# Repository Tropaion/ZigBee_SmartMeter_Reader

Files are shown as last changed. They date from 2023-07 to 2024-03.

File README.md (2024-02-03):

# ZigBee_SmartMeter_Reader
This is an open-source ZigBee device based on the new ESP32-C6 to collect data from smartmeters using the DLMS/COSEM protocol.

Ever since I got the smartmeter "Sagemcom T-210D" with the P1 user interface, I wanted to integrate it into my ZigBee network.
Since I didn't find any existing solution, I decided to develop my own.

If someone is interested in buying an assembled PCB, pm me.
Currently I have one board with external antenna available.

THE PROJECT IS STILL WIP.

# Hardware
View the latest [PCB Interactive BOM](https://htmlpreview.github.io/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).

You can also view the latest [Schematic](https://kicanvas.org/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) or [Layout](https://kicanvas.org/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).

The same hardware could also be used with WLAN and ESPHome.

<p float="left">
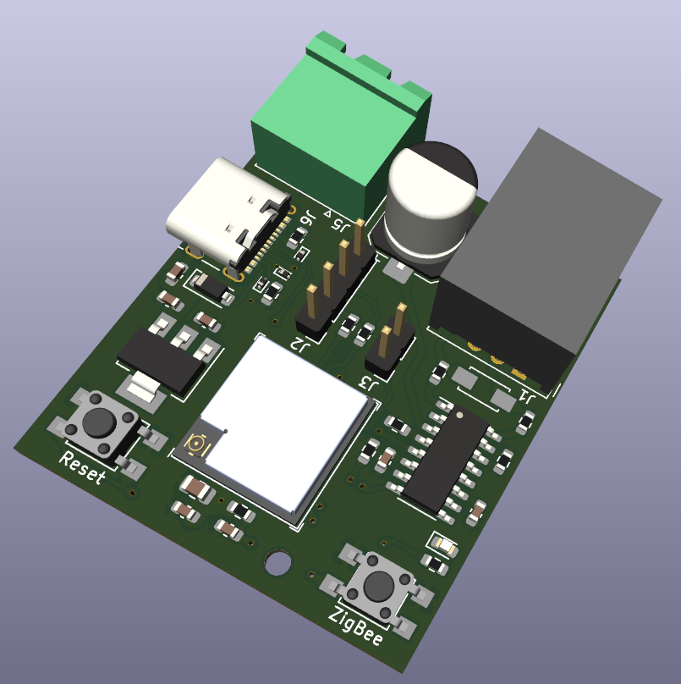
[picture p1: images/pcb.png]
  
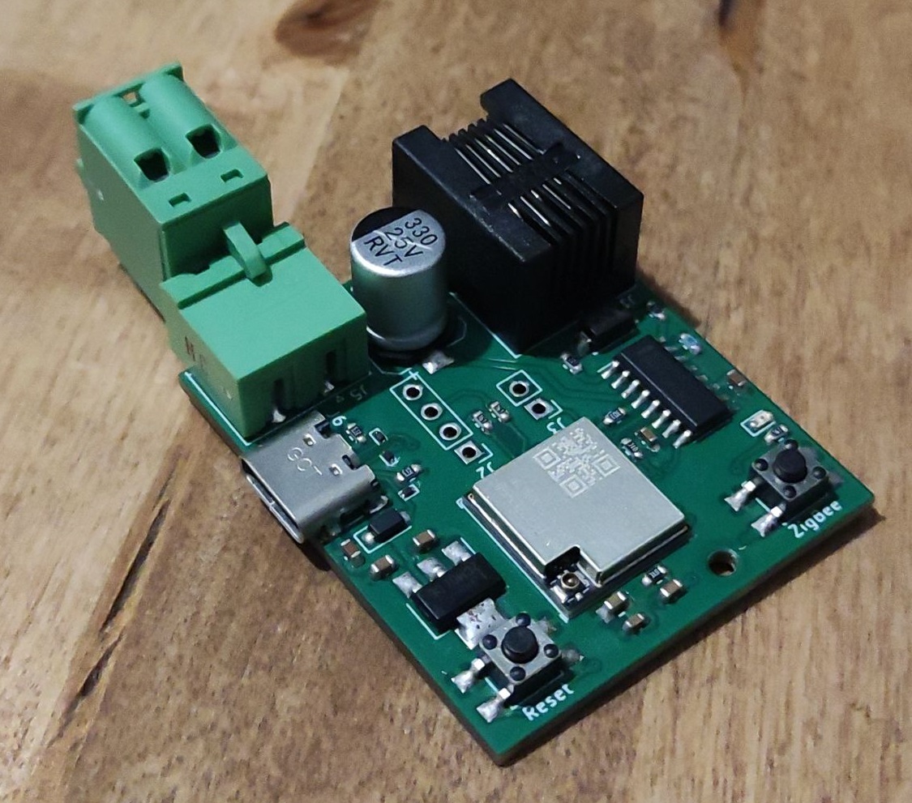
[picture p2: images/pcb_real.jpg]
  
</p>

For this project, I used the [ESP32-C6-MINI-1U](https://www.espressif.com/sites/default/files/documentation/esp32-c6-mini-1_mini-1u_datasheet_en.pdf).
I chose the version with an external antenna, since, in most cases, the devices will be mounted in an isolated meter box. And, since many of them are made of metal (Faraday cage), like in my case, 
I opted for an external antenna to mount on the outside of the meter box.

To provide easy flashing and debugging the USB-C-Socket is connected to the ESP internal USB-JTAG-Converter.
In the case that the converter is not working, the UART0 programming interface is connected to J2 and J3, which will not be assembled.

For production use in the meter box, only the 5V supply terminal (J5) which in my case will be connected to a 5V DIN Power Supply and RJ12 (J1) cable going to the smartmeter is needed.

Since most smartmeters send encrypted data, you probably need to request an decryption key from your provider.
This key has to be configured in the software. The current plan for this is to provide a simple configuration terminal which is accessible via the USB-C-Socket.

# Software
The software will be separated into three core components/libraries.
Each will be individually tested and then combined.
- [x] human_interface - handles button input and led (working)
- [x] zigbee - handles zigbee basic functions
- [x] zigbee_electricity_meter - handles everything zigbee and electricity meter related (cluster)
- [ ] smartmeter - read data via uart, parse layers and decrypt data

Possible additional functionalities:
- [ ] zigbee_ota - updating firmware via zigbee
- [ ] configuration_console - usb console to configure device (decryption key)

OR
- [ ] zigbee custom configuration cluster - cluster configure device (decryption key)

## Structure of SmartMeter data
How the data is handled is a bit complicated and consists of three layers:
- MBUS-Layer
- DLMS-Layer
- OBIS-Layer

Each layer will be handled by a parser.

See the diagram to understand the structure and how the parser handles the data:
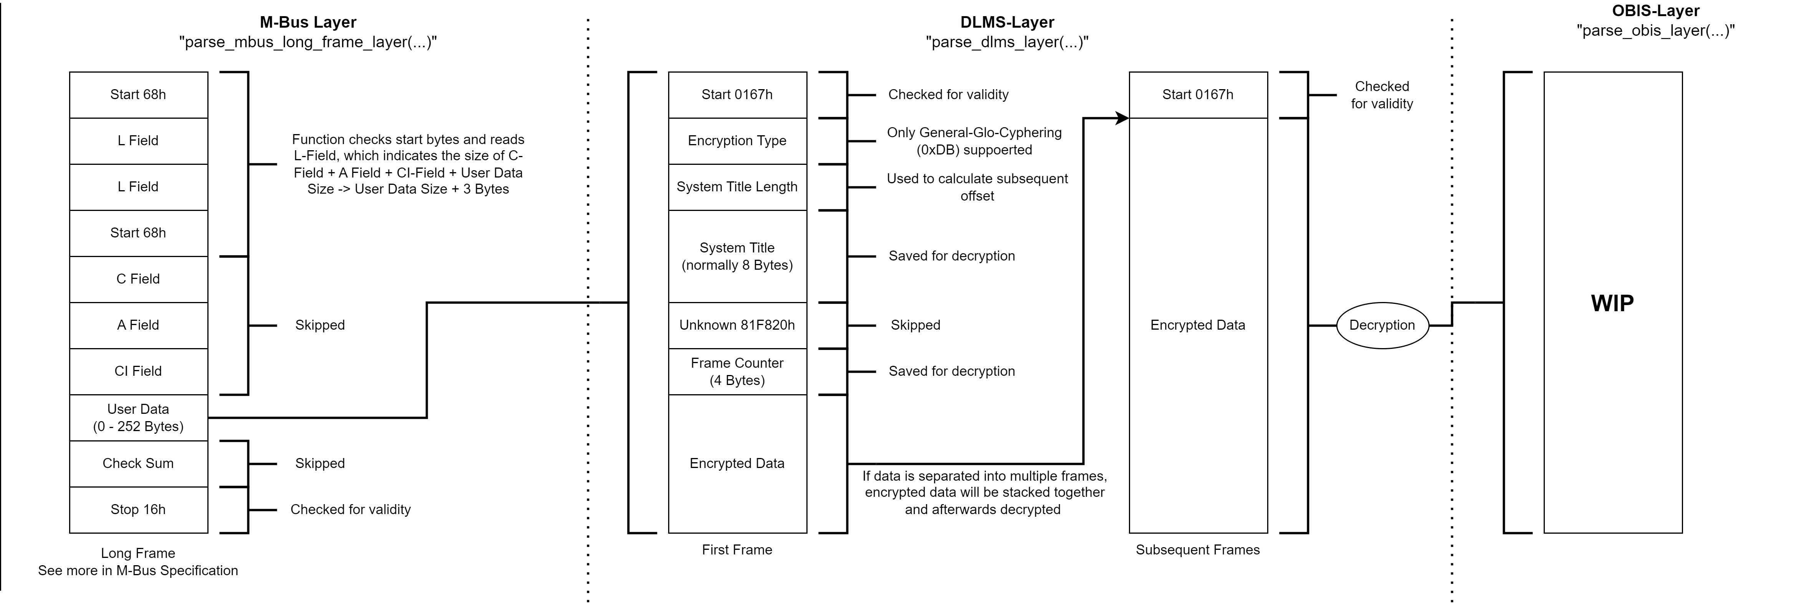
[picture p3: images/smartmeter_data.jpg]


## Sources
 * [esphome-dlms-meter](https://github.com/DomiStyle/esphome-dlms-meter)
 * [SmartMeter P1 Interface](https://www.netz-noe.at/Download-(1)/Smart-Meter/218_9_SmartMeter_Kundenschnittstelle_lektoriert_14.aspx)
 * [M-Bus Specification, Page 22+](https://m-bus.com/assets/downloads/MBDOC48.PDF)
 * [ZigBee Home Automation Profile](https://community.nxp.com/pwmxy87654/attachments/pwmxy87654/wireless-connectivity/698/1/075367r03ZB_AFG-Home_Automation_Profile_for_Public_Download.pdf)
 * [ZigBee Cluster Library Specification](https://zigbeealliance.org/wp-content/uploads/2019/12/07-5123-06-zigbee-cluster-library-specification.pdf)

# Enclosue
The first version of the enclosure is released and now in printing.

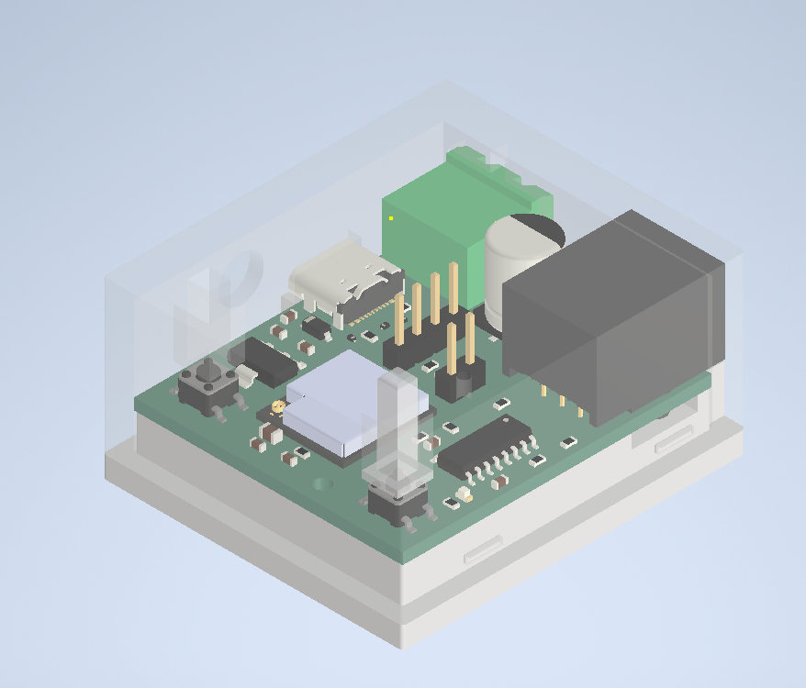
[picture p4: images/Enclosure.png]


# Attribution
Thanks to EspressIf for sponsoring two samples of [ESP32-C6-MINI-1U](https://www.espressif.com/sites/default/files/documentation/esp32-mini-1_datasheet_en.pdf).

Thanks to [PCBWay](https://www.pcbway.com/) for sponsoring the production of the PCB and Stencil for v0.2. It was my first time using their service and they have nice customer service and great build quality. The image in the hardware section shows the result of v0.2.

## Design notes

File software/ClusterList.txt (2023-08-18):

https://docs.espressif.com/projects/esp-zigbee-sdk/en/latest/esp32/introduction.html
https://zigbeealliance.org/wp-content/uploads/2019/12/07-5123-06-zigbee-cluster-library-specification.pdf

 == Values received from SmartMeter and fitting Cluster + Attribute for it ==
0x0702 - Metering Clusteer (Smart Energy -> Metering), S. 592 - not supported

Attribute Set 0x00: Reading Information Set (S. 594)
power factor: 0x0006 PowerFactor
active energy A+ (Wh): ????
active energy A- (Wh): ????
electrical power P- (W): ????

0x0B04 - Electrical Measurement Cluster (Measurement and Sending), S. 298 - already supported
https://docs.espressif.com/projects/esp-zigbee-sdk/en/latest/esp32/api-reference/zcl/esp_zigbee_zcl_electrical_meas.html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

Attribute Set 0x03: AC (Non-phase Specific) Measurements (S. 303)
electrical power P+ (W): 0x0304 TotalActivePower

Attribute Set 0x05: AC (Single Phase or Phase A) Measurements (S. 306)
voltage L1: 0x0505 RMSVoltage
current L1: 0x0508 RMSCurrent

Attribute Set 0x09: AC Phase B Measurements (S. 313)
voltage L2: 0x0905 RMSVoltagePhB
current L2: 0x0908 RMSCurrentPhB

Attribute Set 0x0A: AC Phase C Measurements
voltage L3: 0x0A05 RMSVoltagePhB
current L3: 0x0A08 RMSCurrentPhB

Similar device signature:
{
  "node_descriptor": "NodeDescriptor(logical_type=<LogicalType.Router: 1>, complex_descriptor_available=0, user_descriptor_available=0, reserved=0, aps_flags=0, frequency_band=<FrequencyBand.Freq2400MHz: 8>, mac_capability_flags=<MACCapabilityFlags.FullFunctionDevice|MainsPowered|RxOnWhenIdle|AllocateAddress: 142>, manufacturer_code=4417, maximum_buffer_size=66, maximum_incoming_transfer_size=66, server_mask=10752, maximum_outgoing_transfer_size=66, descriptor_capability_field=<DescriptorCapability.NONE: 0>, *allocate_address=True, *is_alternate_pan_coordinator=False, *is_coordinator=False, *is_end_device=False, *is_full_function_device=True, *is_mains_powered=True, *is_receiver_on_when_idle=True, *is_router=True, *is_security_capable=False)",
  "endpoints": {
    "1": {
      "profile_id": "0x0104",
      "device_type": "0x010a",
      "input_clusters": [
        "0x0000",
        "0x0003",
        "0x0004",
        "0x0005",
        "0x0006",
        "0x0702",
        "0x0b04",
        "0xe000",
        "0xe001"
      ],
      "output_clusters": [
        "0x000a",
        "0x0019"
      ]
    }
  },
  "manufacturer": "_TZ3000_2putqrmw",
  "model": "TS011F",
  "class": "zhaquirks.tuya.ts011f_plug.Plug"
}

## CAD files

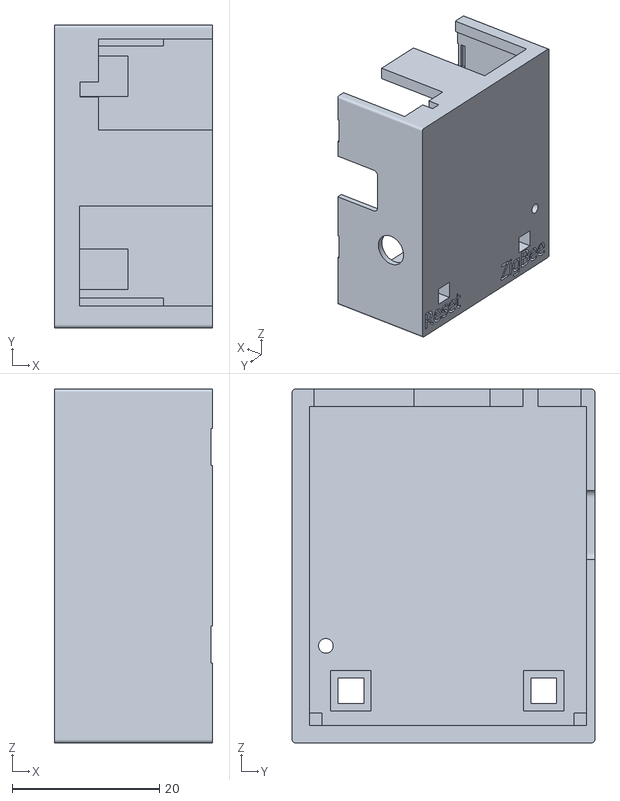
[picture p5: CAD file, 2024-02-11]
enclosure/external_antenna/Enclosure_Top.stl
21.5 x 41.2 x 48.1

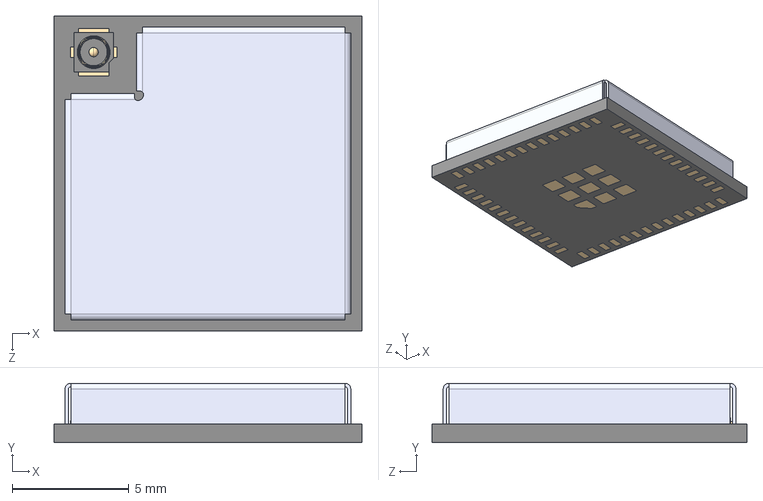
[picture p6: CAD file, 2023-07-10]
hardware/external_antenna/custom_components/3d/ESP32-MINI-1U-N4.STEP
13.2 x 2.55 x 13.5 mm

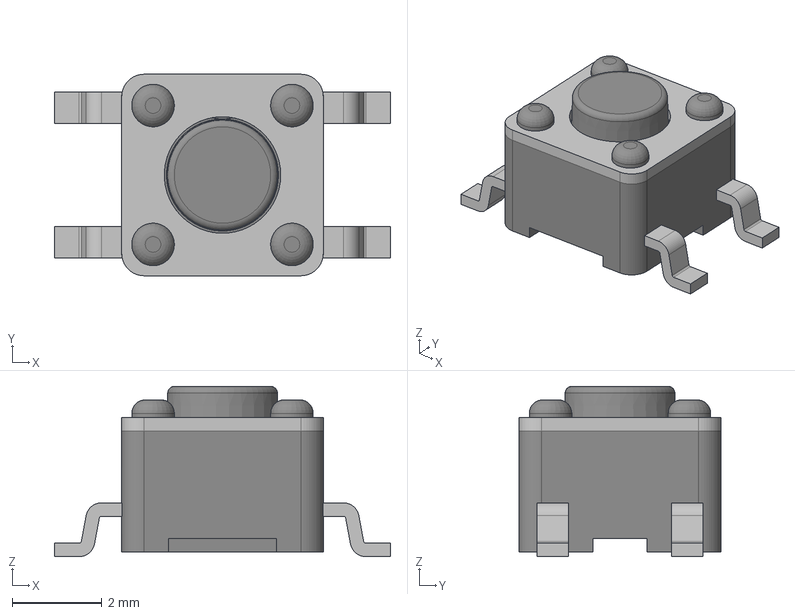
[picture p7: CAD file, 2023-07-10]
hardware/onboard_antenna/custom_components/3d/SW_SPST_TL3305A.step
7.50 x 4.50 x 3.80 mm

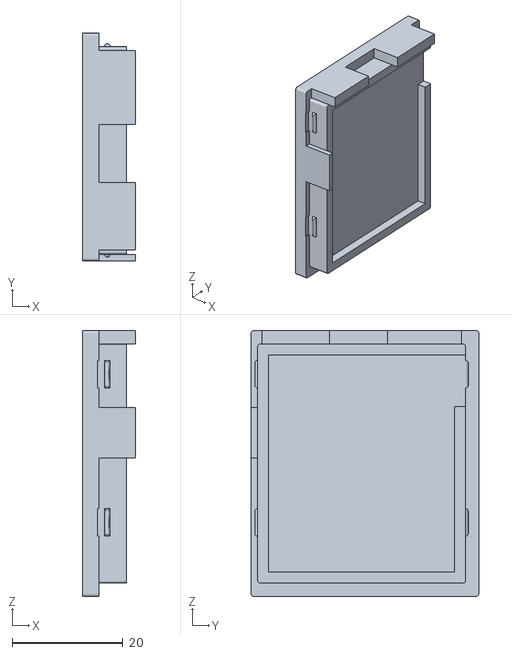
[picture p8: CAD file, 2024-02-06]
enclosure/external_antenna/Enclosure_Bottom.stl
9.60 x 41.2 x 48.1

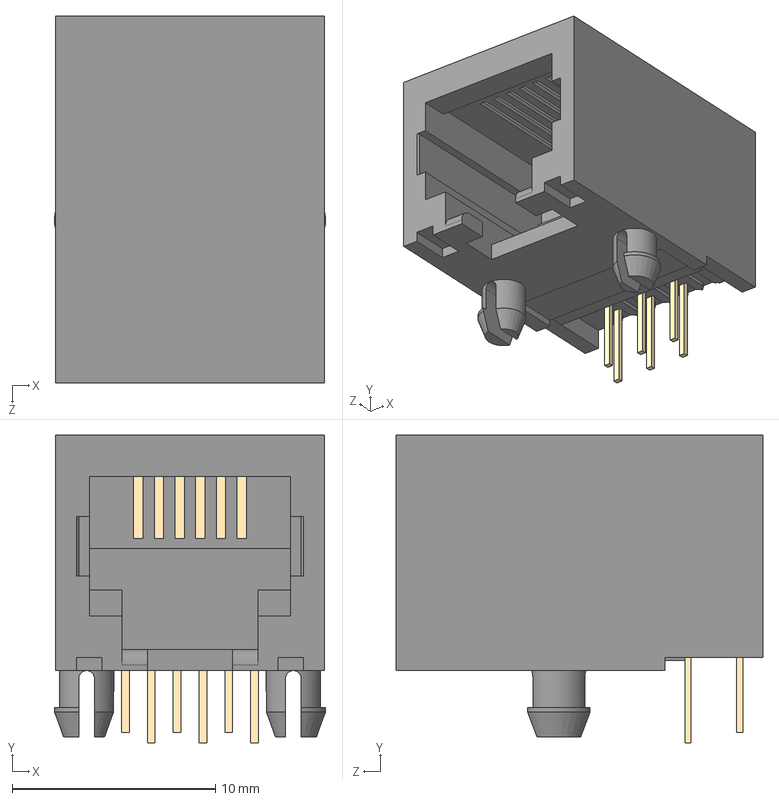
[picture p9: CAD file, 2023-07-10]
hardware/external_antenna/custom_components/3d/RJ12.step
13.3 x 15.1 x 18.0 mm

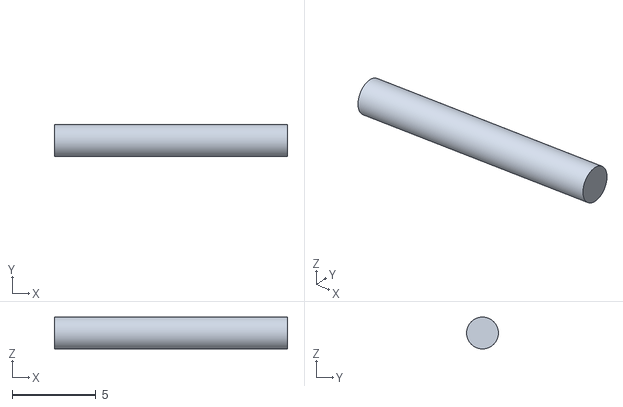
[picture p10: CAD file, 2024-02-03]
enclosure/external_antenna/Enclosure_Lightsaber.stl
13.9 x 1.90 x 1.90

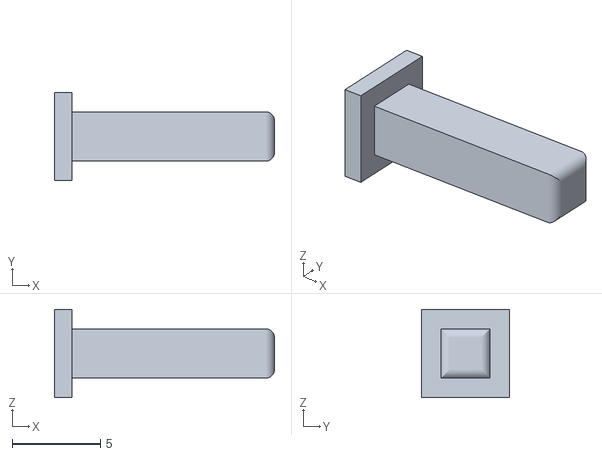
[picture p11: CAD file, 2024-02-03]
enclosure/external_antenna/Enclosure_Button.stl
12.5 x 5.00 x 5.00

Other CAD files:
enclosure/external_antenna/Enclosure_Bottom.ipt
enclosure/external_antenna/Enclosure_Button.ipt
enclosure/external_antenna/Enclosure_Lightsaber.ipt
enclosure/external_antenna/Enclosure_Top.ipt

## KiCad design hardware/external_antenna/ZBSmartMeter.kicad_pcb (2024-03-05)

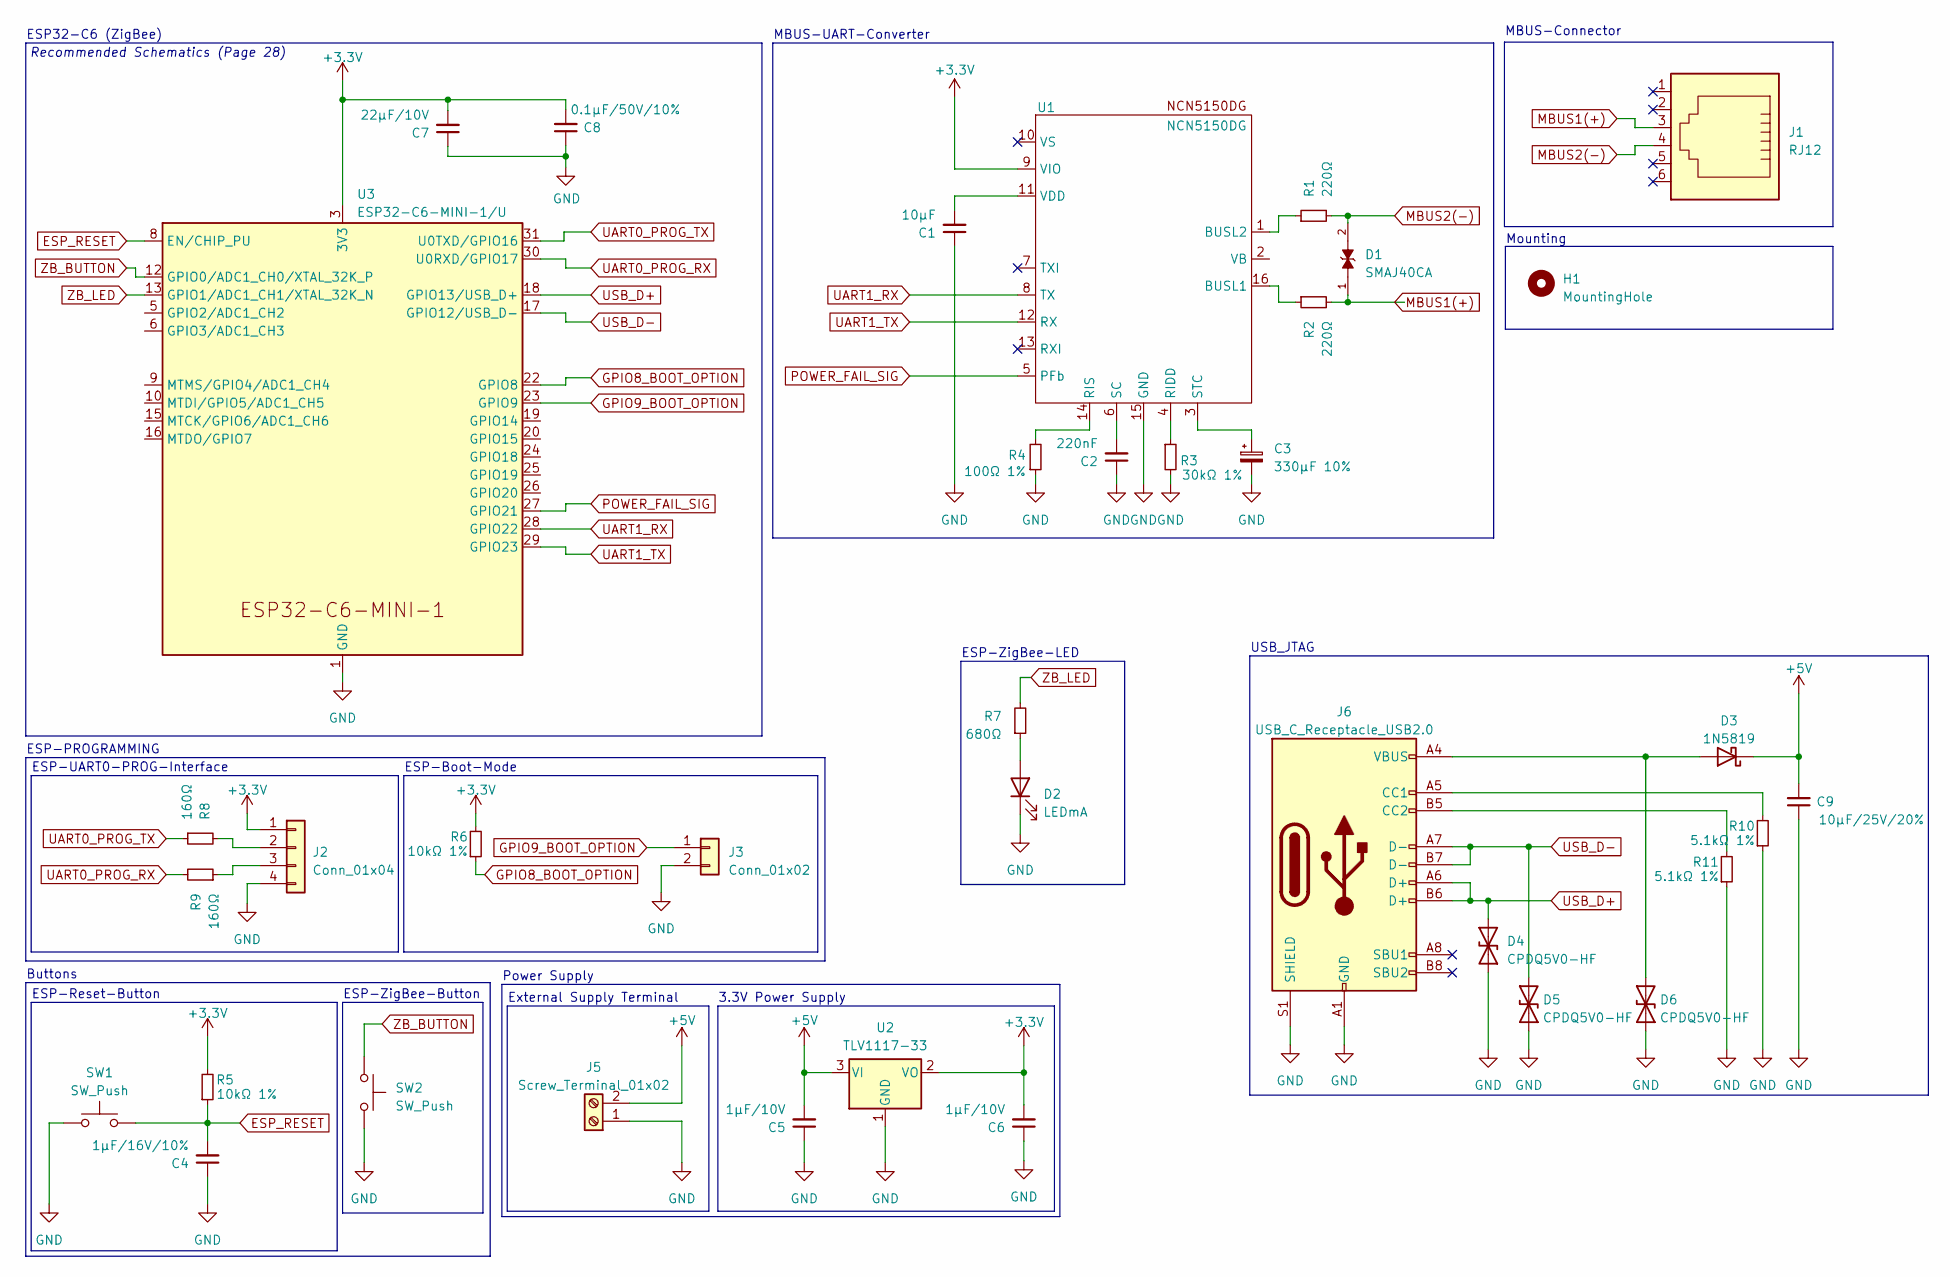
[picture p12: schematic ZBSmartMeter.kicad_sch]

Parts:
C1: 10µF; C_0603_1608Metric
C2: 220nF; C_0603_1608Metric
C3: 330µF 10%; CP_Elec_8x10.5
C4: 1µF/16V/10%; C_0603_1608Metric
C5, C6: 1µF/10V; C_0603_1608Metric
C7: 22µF/10V; C_0805_2012Metric
C8: 0.1µF/50V/10%; C_0603_1608Metric
C9: 10µF/25V/20%; C_0603_1608Metric
D1: SMAJ40CA; DIOM4325X250N; PARTREV S2102; Mouser 576-SMAJ40CA
D2: LEDmA; LED_0603_1608Metric
D3: 1N5819; D_SOD-123; Mouser 621-1N5819HW-F
D4, D5, D6: CPDQ5V0-HF; D_SOD-923; Mouser 750-CPDQ5V0-HF
H1: MountingHole; MountingHole_2.2mm_M2
J1: RJ12; RJ12_Amphenol_54601; Mouser 649-54601-906WPLF
J2: Conn_01x04; PinHeader_1x04_P2.54mm_Vertical
J3: Conn_01x02; PinHeader_1x02_P2.54mm_Vertical
J5: Screw_Terminal_01x02; PhoenixContact_MSTBA_2,5_2-G_1x02_P5.00mm_Horizontal; Mouser 651-1923759 and 651-1942154
J6: USB_C_Receptacle_USB2.0; USB_C_Receptacle_GCT_USB4105-xx-A_16P_TopMnt_Horizontal; Mouser 640-USB4105-GF-A
R1, R2: 220Ω; R_0603_1608Metric
R3: 30kΩ 1%; R_0603_1608Metric
R4: 100Ω 1%; R_0603_1608Metric
R5, R6: 10kΩ 1%; R_0603_1608Metric
R7: 680Ω; R_0603_1608Metric
R8, R9: 160Ω; R_0603_1608Metric
R10, R11: 5.1kΩ 1%; R_0603_1608Metric
SW1, SW2: SW_Push; SW_SPST_TL3305A; Mouser 612-TL3305AF160QG
U1: NCN5150DG; SOIC-16_3.9x9.9mm_P1.27mm; Mouser 863-NCN5150DR2G
U2: TLV1117-33; SOT-223-3_TabPin2; Mouser 595-TLV1117LV33DCYT
U3: ESP32-C6-MINI-1/U; ESP32-C6-MINI-1U

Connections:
+3.3V: C6.2, C7.2, C8.2, J2.1, R5.2, R6.2, U1.9 (VIO), U2.2 (VO), U3.3 (3V3)
+5V: C5.2, C9.2, D3.1 (K), J5.2, U2.3 (VI)
ESP_RESET: C4.2, R5.1, SW1.2, U3.8 (EN/CHIP_PU)
GND: C1.1, C2.1, C3.2, C4.1, C5.1, C6.1, C7.1, C8.1, C9.1, D2.1 (K), D4.1 (A1), D5.1 (A1), D6.1 (A1), J2.4, J3.2, J5.1, J6.A1 (GND), J6.A12 (GND), J6.B1 (GND), J6.B12 (GND), J6.S1 (SHIELD), R3.2, R4.1, R10.1, R11.1, SW1.1, SW2.2, U1.15 (GND), U2.1 (GND), U3.1 (GND), U3.2 (GND), U3.11 (GND), U3.14 (GND), U3.36 (GND), U3.37 (GND), U3.38 (GND), U3.39 (GND), U3.40 (GND), U3.41 (GND), U3.42 (GND), U3.43 (GND), U3.44 (GND), U3.45 (GND), U3.46 (GND), U3.47 (GND), U3.48 (GND), U3.49 (GND), U3.50 (GND), U3.51 (GND), U3.52 (GND), U3.53 (GND)
GPIO8_BOOT_OPTION: R6.1, U3.22 (GPIO8)
GPIO9_BOOT_OPTION: J3.1, U3.23 (GPIO9)
MBUS1(+): D1.1, J1.3, R2.2
MBUS2(-): D1.2, J1.4, R1.2
unnamed: D2.2 (A), R7.1
unnamed: D3.2 (A), D6.2 (A2), J6.A4 (VBUS), J6.A9 (VBUS), J6.B4 (VBUS), J6.B9 (VBUS)
unnamed: J2.2, R8.2
unnamed: J2.3, R9.1
unnamed: J6.A5 (CC1), R10.2
unnamed: J6.B5 (CC2), R11.2
unnamed: R2.1, U1.16 (BUSL1)
unnamed: R1.1, U1.1 (BUSL2)
unnamed: R3.1, U1.4 (RIDD)
unnamed: R4.2, U1.14 (RIS)
unnamed: C2.2, U1.6 (SC)
unnamed: C3.1, U1.3 (STC)
unnamed: C1.2, U1.11 (VDD)
POWER_FAIL_SIG: U1.5 (PFb), U3.27 (GPIO21)
UART0_PROG_RX: R9.2, U3.30 (U0RXD/GPIO17)
UART0_PROG_TX: R8.1, U3.31 (U0TXD/GPIO16)
UART1_RX: U1.8 (TX), U3.28 (GPIO22)
UART1_TX: U1.12 (RX), U3.29 (GPIO23)
USB_D+: D4.2 (A2), J6.A6 (D+), J6.B6 (D+), U3.18 (GPIO13/USB_D+)
USB_D-: D5.2 (A2), J6.A7 (D-), J6.B7 (D-), U3.17 (GPIO12/USB_D-)
ZB_BUTTON: SW2.1, U3.12 (GPIO0/ADC1_CH0/XTAL_32K_P)
ZB_LED: R7.2, U3.13 (GPIO1/ADC1_CH1/XTAL_32K_N)

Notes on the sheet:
Mounting
ESP-ZigBee-Button
MBUS-Connector
3.3V Power Supply
ESP-UART0-PROG-Interface
External Supply Terminal
ESP-PROGRAMMING
USB_JTAG
ESP-ZigBee-LED
Buttons
ESP-Reset-Button
ESP-Boot-Mode
MBUS-UART-Converter
ESP32-C6 (ZigBee)
Recommended Schematics (Page 28)
Power Supply

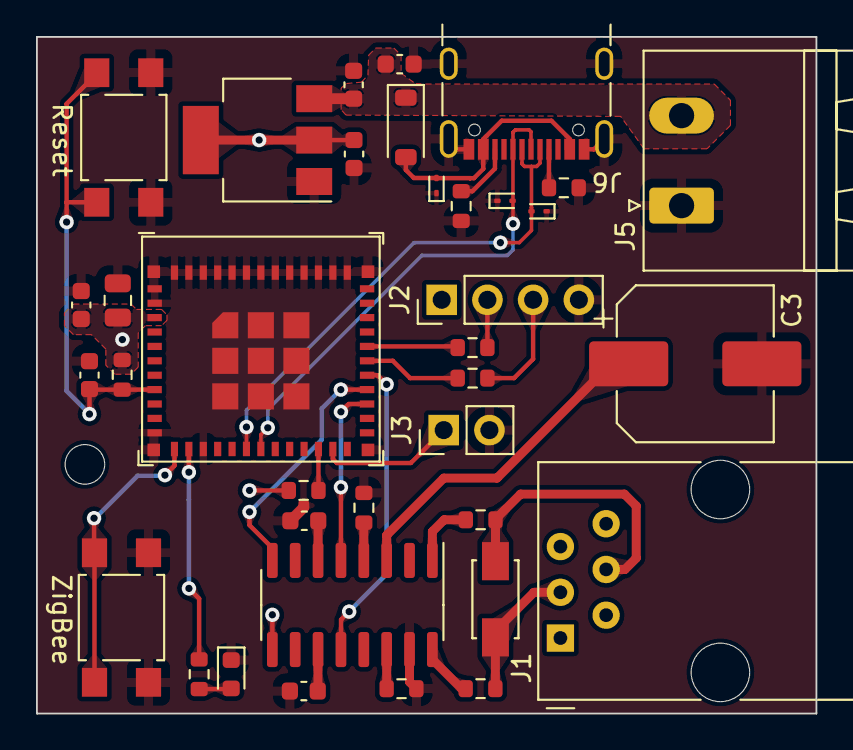
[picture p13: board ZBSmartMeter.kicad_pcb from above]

Board: 2 copper layers, 43.3 x 37.6 mm, 37 parts (0 on the bottom side), 30 nets.

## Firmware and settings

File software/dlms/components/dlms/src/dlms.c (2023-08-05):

/**
 * @file dlms.c
 * 
 * @copyright Copyright (c) 2023
 * 
 */

#include <stdio.h>
#include <string.h>

/* Logging */
#include "esp_log.h"
static const char* TAG = "dlms";

/* Header */
#include "dlms.h"

/* FreeRTOS Libraries */
#include "freertos/FreeRTOS.h"
#include "freertos/task.h"
#include "freertos/queue.h"

/* UART Library */
#include "driver/uart.h"
#include "hal/uart_hal.h" /* for interrupt mask defines */

/* Encryption Library */
#include "mbedtls/gcm.h"

/* UART Event Queue */
static QueueHandle_t uart1_queue = NULL;

/* SMALL INFODUMP */
/* Structure of data and how it's processed */
/* 1. Physical Layer -> UART */
/* 2. MBUS-Layer -> parse with "parse_mbus_long_frame_layer", supports multiple frames, returns user data */
/* 3. DLMS (Application)-Layer -> decrypt and parse with "todo" */

/* ===== Physical Layer (UART) ===== */
/* UART Event Handler */
//TODO: Timeout Event
static void uart_event_task(void *pvParameters)
{
    /* Store current event */
    uart_event_t event;

    /* Buffer for event data */
    uint8_t buff[DATA_BUFFER_SIZE];

    for(;;)
    {
        /* Loop infinitely and check for event */
        if(xQueueReceive(uart1_queue, (void *)&event, (TickType_t)portMAX_DELAY))
        {
            /* Set buffer to zero */
            bzero(&buff, DATA_BUFFER_SIZE);

            /* Switch according to event type */
            switch(event.type)
            {
                /* Received data */
                case UART_DATA:
                    /* Receive bytes from uart */
                    uart_read_bytes(UART_PORT_NUMBER, &buff, event.size, portMAX_DELAY);

                    /* Dump bytes to console */
                    ESP_LOG_BUFFER_HEX(TAG, &buff, event.size);
                    break;
                /* Other events */
                default:
                    /* Write event to log */
                    ESP_LOGI(TAG, "UART Event Type: %d", event.type);
                    break;
            }
        }
    }
    /* Delete this task */
    vTaskDelete(NULL);
}

/* ===== M-BUS-Layer ===== */
/**
 * @brief Parser for MBUS-Layer, only long frames!
 * 
 * @param payload data from physical layer
 * @param payload_size size of data from physical layer
 * @param user_data extracted user data
 * @param user_data_size size of extracted user data
 */
static esp_err_t parse_mbus_long_frame_layer(uint8_t* payload, uint16_t payload_size, uint8_t* user_data, uint16_t* user_data_size)
{
    /* Offset if multiple frames need to be parsed */
    uint16_t curr_offset = 0;
    
    /* New data, set user data size to zero */
    *user_data_size = 0;
    
    /* Loop throught payload and that minimum frame size does not exceed rest of payload */
    while(curr_offset + MBUS_HEADER_LENGTH + MBUS_FOOTER_LENGTH < payload_size)
    {
        /* Check start fields integrity */
        if((payload[curr_offset + MBUS_START1_OFFSET] != MBUS_START_VALUE) || (payload[curr_offset + MBUS_START2_OFFSET] != MBUS_START_VALUE))
        {
            ESP_LOGE(TAG, "Invalid start bytes!");
            return ESP_FAIL;
        }
        
        /* Check L-fields integrity (length) */
        if(payload[curr_offset + MBUS_LENGTH1_OFFSET] != payload[curr_offset + MBUS_LENGTH2_OFFSET])
        {
            ESP_LOGE(TAG, "Length byes do not match!");
            return ESP_FAIL;
        }
        
        /* Get user data size (l-field) */
        uint8_t l_field = payload[curr_offset + MBUS_LENGTH1_OFFSET] - MBUS_USER_DATA_SIZE_OFFSET;
        
        /* Check Stop-field integrity */
        if(payload[curr_offset + MBUS_HEADER_LENGTH + l_field + MBUS_FOOTER_LENGTH - 1] != MBUS_STOP_VALUE)
        {
            ESP_LOGE(TAG, "Invalid stop byte!");
            return ESP_FAIL;
        }
        
        /* Frame check passed, everything ok, copy user data to buffer */
        memcpy(&user_data[*user_data_size], &payload[curr_offset + MBUS_USER_DATA_OFFSET], l_field);
     
        /* Set offset to next frame */
        curr_offset += MBUS_HEADER_LENGTH + l_field + MBUS_FOOTER_LENGTH;
        
        /* Increase user data size */
        *user_data_size += l_field;
    }
    return ESP_OK;
}

/* ===== DLMS Layer ===== */
static uint8_t gue_key[GUE_KEY_LENGTH] = {0x52, 0xFC, 0xF7, 0x0B, 0xC3, 0x94, 0x9B, 0x61, 0x3E, 0xC9, 0xE7, 0xB1, 0x5F, 0xAD, 0x55, 0xEF};

static esp_err_t apdu_decrypt(uint8_t* user_data, uint16_t user_data_size)
{
    /* Encrypted data buffer */
    uint8_t encrypted_data[DATA_BUFFER_SIZE];
    uint16_t encrypted_data_size = 0;

    /* Frame counter for decryption */
    uint8_t frame_counter[DLMS_FRAME_COUNTER_SIZE];

    /* ===== GET RELEVANT DATA ===== */
    /* This part can be different for other smartmeters */

    /* Get frame counter */
    memcpy(&frame_counter[0], &user_data[DLMS_FRAME_COUNTER_OFFSET], DLMS_FRAME_COUNTER_SIZE);

    /* Copy first frame, to get relevant data to decrypt */
    /* Calculate size of first frame */
    if(user_data_size < DLMS_MAX_SIZE)
    {
        encrypted_data_size = user_data_size - DLMS_FIRST_FRAME_OFFSET;
    }
    else
    {
        encrypted_data_size = DLMS_MAX_SIZE - DLMS_FIRST_FRAME_OFFSET;
    }
    /* Copy first frame */
    memcpy(&encrypted_data[0], &user_data[DLMS_FIRST_FRAME_OFFSET], encrypted_data_size);

    /* Check if data consists of multiple frames */
    for(int i = DLMS_MAX_SIZE; user_data_size > i; i += DLMS_MAX_SIZE)
    {
        uint16_t frame_size;

        /* Calculate frame size */
        if(user_data_size > (i + DLMS_MAX_SIZE))
        {
            frame_size = DLMS_MAX_SIZE - DLMS_SECONDARY_FRAME_OFFSET;
        }
        else
        {
            frame_size = user_data_size - i - DLMS_SECONDARY_FRAME_OFFSET;
        }
        /* Copy frame */
        memcpy(&encrypted_data[encrypted_data_size], &user_data[i + DLMS_SECONDARY_FRAME_OFFSET], frame_size);
        
        /* Increment data size */
        encrypted_data_size += frame_size;
    }

    printf("Encrypted data Size: %d\n", encrypted_data_size);
    for (int i = 0; i < encrypted_data_size; i++)
    {
        printf("%02X", encrypted_data[i]);
    }

    /* ===== DECRYPT DATA ===== */
    //mbedtls_gcm_context aes;
    return ESP_OK;
}

static esp_err_t apdu_pars()
{
    return ESP_OK;
}
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

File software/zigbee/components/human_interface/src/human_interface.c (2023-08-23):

/**
 * @file human_interface.c
 * 
 * @copyright Copyright (c) 2023
 * 
 */

#include <stdio.h>

/* Logging */
#include "esp_log.h"
static const char* TAG = "human_interface";

/* Header */
#include "human_interface.h"

/* Button Library */
#include "iot_button.h"

/* Led Library */
#include "led_indicator.h"

/* Led Handle */
static led_indicator_handle_t led_handle = NULL;

/* ===== BUTTON FUNCTIONS ===== */
esp_err_t button_init(bttn_cb_t button_cb)
{
    /* Configuration */
    button_config_t button_config = {
        .type = BUTTON_TYPE_GPIO,
        .long_press_time = BTTN_LONG_PRESS_TIME_MS,
        .gpio_button_config = {
            .gpio_num = BTTN_GPIO_NUM,
            .active_level = 0,
        },
    };

    /* Create button */
    button_handle_t button_handle = iot_button_create(&button_config);

    /* Check for error */
    if(button_handle == NULL)
    {
        ESP_LOGE(TAG, "No button handle!");
        return ESP_FAIL;
    }

    /* Register long press button callback */
    return iot_button_register_cb(button_handle, BUTTON_LONG_PRESS_START, (button_cb_t)button_cb, NULL);
}

/* ===== LED FUNCTIONS ===== */
esp_err_t led_init()
{
    /* reset animation */
    static const blink_step_t blink_reset[] = {
        {LED_BLINK_HOLD, LED_STATE_ON, 500},
        {LED_BLINK_HOLD, LED_STATE_OFF, 500},
        {LED_BLINK_LOOP, 0, 0},
    };

    /* resetting device animation */
    static const blink_step_t blink_coupling[] = {
        {LED_BLINK_HOLD, LED_STATE_ON, 1000},
        {LED_BLINK_HOLD, LED_STATE_OFF, 1000},
        {LED_BLINK_LOOP, 0, 0},
    };

    /* sending data animation */
    static const blink_step_t blink_sending_data[] = {
        {LED_BLINK_HOLD, LED_STATE_ON, 500},
        {LED_BLINK_HOLD, LED_STATE_OFF, 0},
        {LED_BLINK_STOP, 0, 0},
    };

    /* start up animation */
    static const blink_step_t blink_start_up[] = {
        {LED_BLINK_HOLD, LED_STATE_ON, 0},
        {LED_BLINK_STOP, 0, 0},
    };

    /* create animation list */
    static blink_step_t const* blink_list[] = {
        [BLINK_RESET] = blink_reset,
        [BLINK_COUPLING] = blink_coupling,
        [BLINK_SENDING_DATA] = blink_sending_data,
        [BLINK_START_UP] = blink_start_up,
    };

    /* GPIO configuration */
    led_indicator_gpio_config_t gpio_config = {
        .gpio_num = LED_GPIO_NUM,
        .is_active_level_high = 1,
    };

    /* blink configuration */
    led_indicator_config_t blink_config = {
        .led_indicator_gpio_config = &gpio_config,
        .mode = LED_GPIO_MODE,
        .blink_lists = blink_list,
        .blink_list_num = LED_BLINK_NUM,
    };

    /* Create handle */
    led_handle = led_indicator_create(&blink_config);

    /* Check for error */
    if(led_handle == NULL)
    {
        ESP_LOGE(TAG, "No led handle!");
        return ESP_FAIL;
    }

    return ESP_OK;
}

esp_err_t led_animation_start(led_blink_type_t type)
{
    return led_indicator_start(led_handle, type);
}

esp_err_t led_animation_stop(led_blink_type_t type)
{
    return led_indicator_stop(led_handle, type);
}

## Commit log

2023-07-10 added hardware
    [ESP32-MINI-1U-N4.STEP, RJ12.step, SW_SPST_TL3305A.step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]
2023-07-10 update hardware + documentation
    [ZBSmartMeter.kicad_pcb]
2023-07-10 Fix gerber
    [ZBSmartMeter.kicad_pcb]
2023-07-18 fixed diode error, improved layout
    [ZBSmartMeter.kicad_pcb, ZBSmartMeter.kicad_sch]
2023-07-18 Update gerber
    [ZBSmartMeter.kicad_pcb]
2023-07-27 Add enclosure files
    [Enclosure_Bottom.ipt, Enclosure_Bottom.stl, Enclosure_Top.ipt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]
2023-07-28 LED to bright, change resistor value
    [ZBSmartMeter.kicad_pcb, ZBSmartMeter.kicad_sch]
2023-08-02 dlms in progress
    [ZBSmartMeter.kicad_pcb, ZBSmartMeter.kicad_sch]
2023-08-02 basic zigbee implementation, merge "human_interface" into zigbee
    [partitions.csv]
2023-08-06 Working dlms parser
    [partitions.csv]
2023-08-07 uart stuff
2023-08-15 Initial hardware design for ESP32-C6-WROOM-1
    [ESP32-MINI-1U-N4.STEP, RJ12.step, SW_SPST_TL3305A.step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]
2023-08-15 Finalize UART event handling
2023-08-15 Improve UART Error handling
    [dlms.h]
2023-08-15 Fix uart task stack size
    [mbus.h]
2023-08-16 Fix UART Loop
2023-08-16 UART Event now working
2023-11-29 editing enclosure
    [Enclosure_Bottom.0006.ipt, Enclosure_Bottom.ipt, Enclosure_Top.0009.ipt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]
2024-02-03 new enclosure
    [Enclosure_Bottom.0006.ipt, Enclosure_Bottom.ipt, Enclosure_Bottom.stl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]
2024-02-03 edit enclosure
    [Enclosure_Bottom.ipt, Enclosure_Bottom.stl, Enclosure_Button.ipt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]
2024-02-06 improved enclosure
    [Enclosure_Bottom.ipt, Enclosure_Bottom.stl, Enclosure_Top.ipt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]
2024-03-05 Bump to KiCad8
    [ZBSmartMeter.kicad_pcb, ZBSmartMeter.kicad_sch]
